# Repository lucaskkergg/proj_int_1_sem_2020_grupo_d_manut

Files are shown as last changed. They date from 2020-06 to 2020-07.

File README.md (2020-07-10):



# Projeto Integrador - Fatec São José dos Campos - Brasil

Projeto integrador de cunho tecnológico e desenvolvimental, o qual a atividade proposta foi desenvolver o "escopo" de uma ferramenta utilizada para a manutenção de uma aeronave.

## - Descrição das pastas:
* __ATAS:__ Contém as ATAS desenvolvidas durante o projeto;
* __Apresentações:__ Contém as apresentações desenvolvidas pelo grupo;
* __CAD:__ Contém os projetos 3D da peça;
* __Calculos:__ Contém os calculos aplicados e utilizados no projeto;
* __Documentos:__ Documentações importantes ao projeto;
* __Git_img:__ Pastá com arquivos para o "README";
* __Imagens:__ Contém imagens referentes ao projeto;
* __Grupo-Delta-Projeto-Integrador:__ Contém os arquivos solicitados pelo professor para avaliação do Pi.

## - Integrantes
* Christian Arilio Bezerra de Queiroz;
* Karen Roithmeier Rodrigues;
* Lucas Sergio de Oliveira;
* Marcio Siqueira Pereira;
* Mayara Carolina Ferreira de Lima;
* Paulo Henrique Conceição Dias.

## - Objetivo

Desenvolvimento de uma ferramenta proposta.

## - Estrutura 3D da mesma:

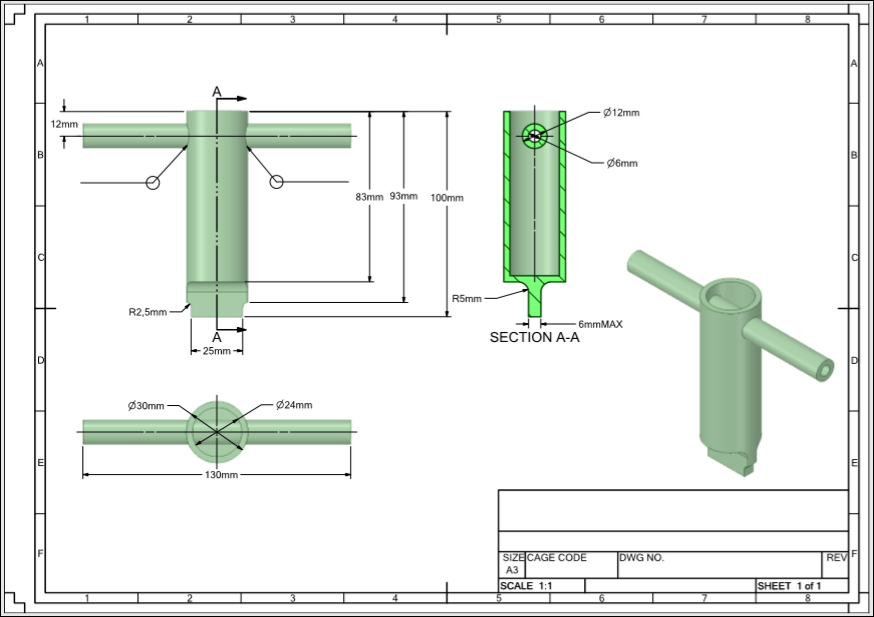
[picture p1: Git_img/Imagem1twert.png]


 ## - Link do vídeo:
 
 https://youtu.be/3H-tNPrEDUI
 ---------------------------------------------------------------------------------------------------------

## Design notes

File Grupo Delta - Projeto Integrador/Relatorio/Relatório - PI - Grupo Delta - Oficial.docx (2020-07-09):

FATEC – FACULDADE DE TECNOLOGIA DE SÃO JOSÉ DOS CAMPOS
PROF. JESSEN VIDAL

Chave de Retenção para Cilindro de Alta Pressão do Trem De Pouso Principal do Helicóptero Pantera

SÃO JOSÉ DOS CAMPOS / SP

1° Semestre - 2020

Chave de Retenção para Cilindro de Alta Pressão do Trem de Pouso Principal do Helicóptero Pantera

INTEGRANTES: CHRISTIAN ARILIO BEZERRA
DE QUEIROZ, KAREN ROITHMEIER RODRIGUES, LUCAS SERGIO DE OLIVEIRA, MÁRCIO SIQUEIRA PEREIRA, MAYARA CAROLINA FERREIRA DE LIMA, PAULO HENRIQUE CONCEIÇÃO DIAS

PROF. ORIENTADOR: ALEXANDRE ZARAMELA

PROF. CLIENTE: FELIX ARLINDO STROTTMANN

CURSO: TÉCNOLOGO EM MANUTENÇÃO DE AERONAVES

SÃO JOSÉ DOS CAMPOS / SP

1° Semestre - 2020

# 1. INTRODUÇÃO

O Projeto Integrador Transversal proposto pela FATEC – Faculdade de Tecnologia de São José dos Campos/SP, tem como objetivo promover ao aluno a oportunidade de desenvolvimento de suas habilidades através de um desafio real, que o leva através da prática a solucionar uma necessidade específica proposta.

No primeiro semestre de 2020, a turma de Manutenção de Aeronaves recém ingressada recebeu o desafio de projetar 5 (cinco) ferramentas que serão utilizadas no Laboratório para montagem e desmontagem do atuador do Trem de Pouso Principal do Helicóptero Pantera. Os alunos dividiram-se em 5 (cinco) grupos, sendo que cada um foi responsável por uma ferramenta específica, tendo como denominação os respectivos grupos: Alfa, Bravo, Charlie, Delta e Foxtrot.

O grupo do presente relatório, Delta, recebeu como desafio o desenvolvimento de projeto da ferramenta “Retaining Key for Cylinder” – Código: PN OU50400, conforme “CMM (Component Maintenance Manual) 32-12-96 Main Landing Gear Leg”. A ferramenta tem como objetivo realizar a montagem do trem de pouso principal retendo o cilindro de alta pressão para aperto de uma porca específica.

# 2. MATERIAIS E MÉTODOS

Após apresentação por parte do professor Félix Arlindo Strottmann e Alexandre Zaramela em relação ao Projeto Integrador Transversal, as turmas dirigiram-se ao laboratório da faculdade para que fosse possível analisar e tomar nota dos componentes que empregam o uso das ferramentas a serem desenvolvidas.

Foi observado o componente que receberia atuação da ferramenta PN OU50400 (figura 1) e, juntamente com o auxílio do CMM (Component Maintenance Manual) 32-12-96, foram realizadas as medições com o paquímetro do Rebaixo do Cilindro (figura 3) do Trem de Pouso Principal do Helicóptero Pantera (figura 2).

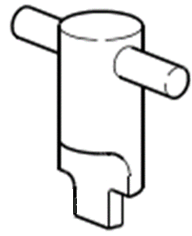
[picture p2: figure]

Figura 1 – Imagem da ferramenta: Chave de Retenção para Cilindro PN OU50400 – Manual CMM: 32-12-96.

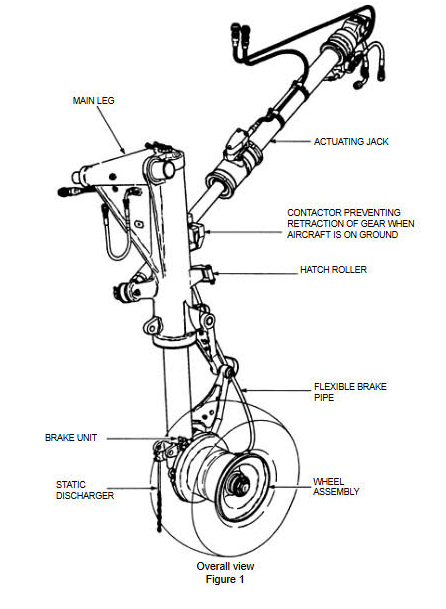
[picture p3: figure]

Figura 2 – Trem de Pouso Principal do Helicóptero Pantera - Manual CMM: 32-12-96, Pág. 39.

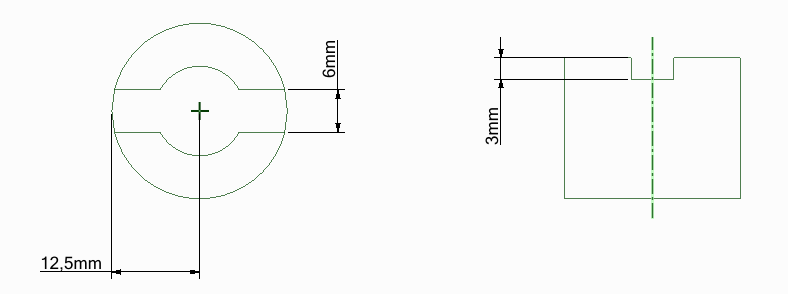
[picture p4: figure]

Figura 3 - Medidas do rebaixo de encaixe do dente da ferramenta no cilindro de alta pressão.

O grupo realizou a medição do Rebaixo no Cilindro, como ilustra a Figura 3, para que se fosse possível dar início ao processo de parametrização da ferramenta. Em posse destes dados, o grupo iniciou um processo de Engenharia reversa, procurando visualizar como era a ferramenta através de imagem presente no manual.

Com as medidas de referência relacionadas ao Dente da ferramenta e, a figura do manual representando como é a aparência da ferramenta, a imaginação entrou em cena, croquis começaram a ser desenvolvidos a mão e em seguida em softwares de modelagem CAD.

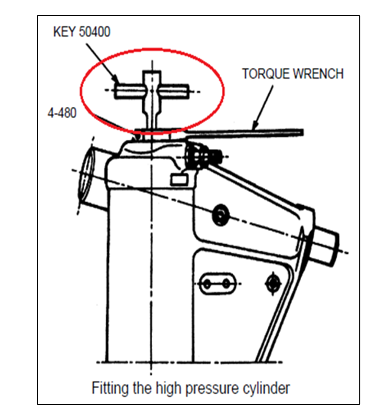
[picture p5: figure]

Figura 4 - Imagem da localização da ferramenta no Trem de Pouso – Manual CMM: 32-12-96.

Os croquis realizados manualmente proporcionaram uma ampla noção para partir à modelagem virtual da ferramenta no CAD. Durante o desenvolvimento do projeto, ocorreram diversas reuniões em grupo com o auxílio do professor orientador Alexandre Zaramela, com o intuito de melhoria dimensional e aproveitamento estrutural. Segue alguns exemplos quanto as dimensões da ferramenta no decorrer do projeto (Figura 5.0 a 5.3).

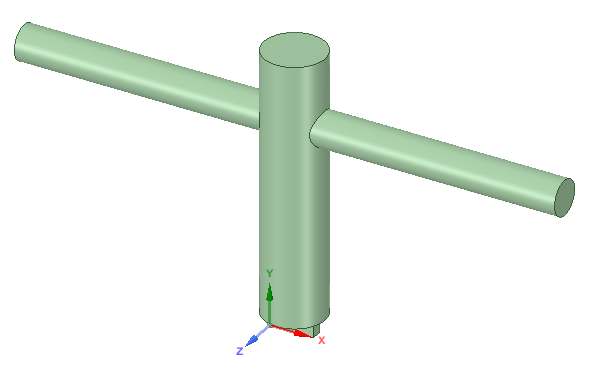
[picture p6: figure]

Figura 5.0 – Imagem do Primeiro Croqui no CAD, partindo do Desenho Técnico Manual – Autoria Própria. SpaceClaim

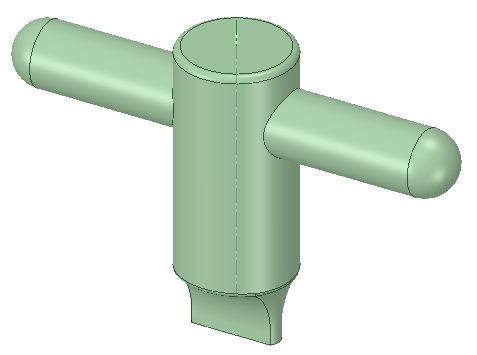
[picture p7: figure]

Figura 5.1 – Imagem do Croqui no CAD, atualizando as medidas com arredondamento na ponta da haste – Autoria Própria. SpaceClaim.

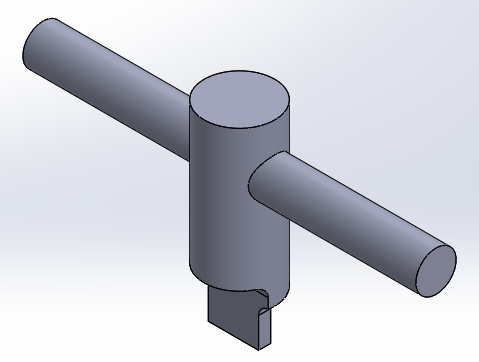
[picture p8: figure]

Figura 5.2 - Imagem do Croqui no CAD, com embasamento no CMM – Autoria Própria. SpaceClaim.

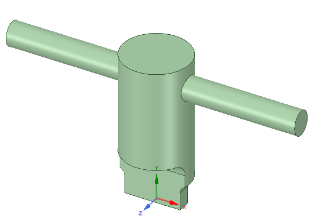
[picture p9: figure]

Figura 5.3 – Imagem do Croqui no CAD, redimensionamento da ferramenta – Autoria Própria. SpaceClaim.

Em uma primeira versão de projeto, as seguintes dimensões na figura abaixo (Figura 6) foram definidas para que se desse início aos cálculos estruturais da ferramenta.

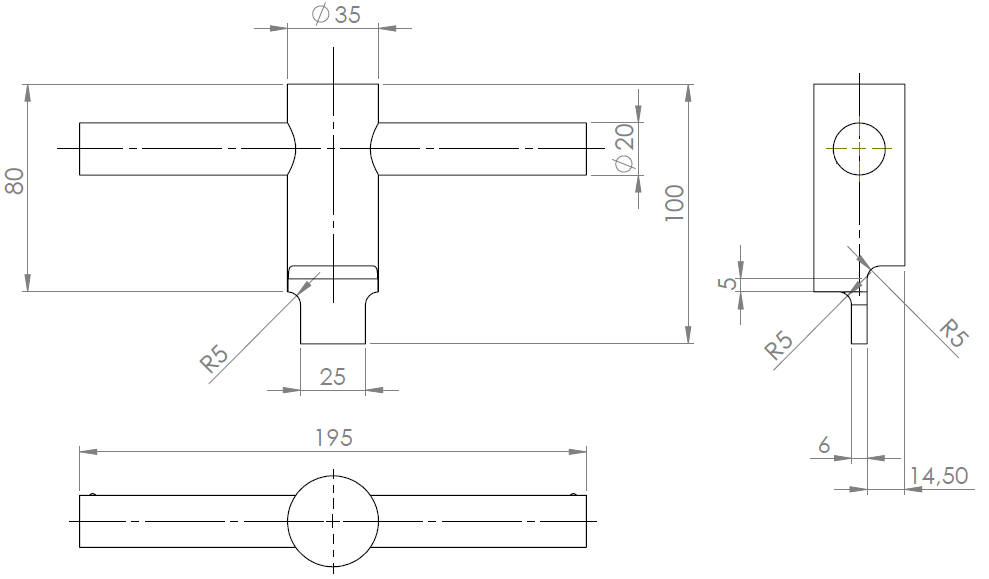
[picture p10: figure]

Figura 6 – Desenho Técnico – Dimensionamento da ferramenta. Autoria Própria. SpaceClaim.

Quanto a nomenclatura adotada para as partes da ferramenta, segue figura abaixo.

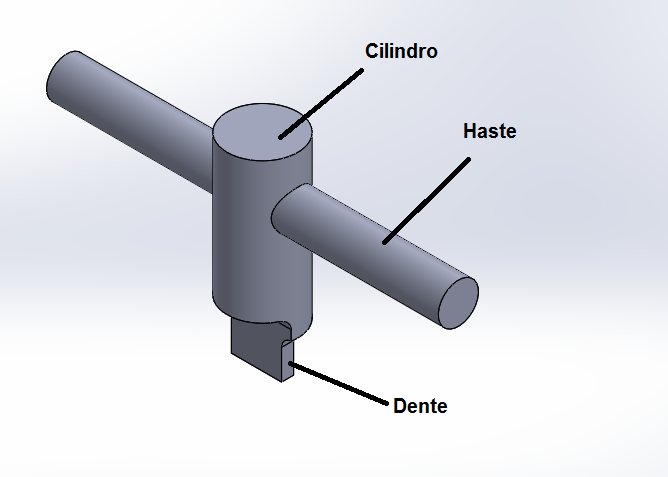
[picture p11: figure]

Figura 7 – Nomenclatura de partes da ferramenta. Autoria Própria. SpaceClaim.

Em relação ao material da ferramenta, foi escolhido o SAE 6150, Aço prata Cromo-Vanádio, pois através de pesquisas e observações em ambientes de trabalho essa liga de aço é a mais utilizada em ferramentas para esforços de torção. O Cromo nesta liga favorece a dureza e a proteção contra oxidação, enquanto o vanádio proporciona alta resistência quanto ao desgaste. Não é necessária a aplicação de tratamento, pois as propriedades mecânicas deste material atendem aos esforços que serão demonstrados adiante através dos cálculos com favorável Margem de Segurança.

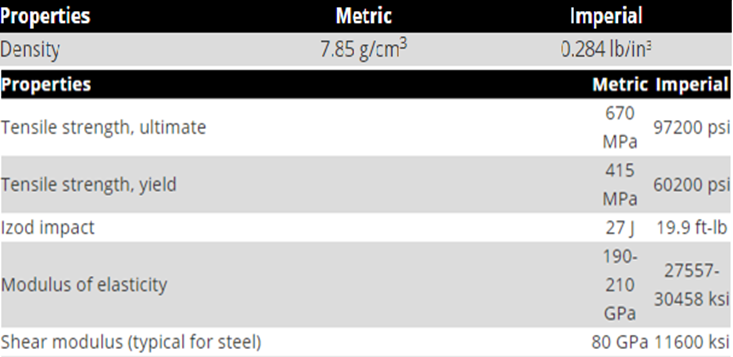
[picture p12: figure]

Propriedades Aço Cromo-Vanádio

. Tabela 1 – Propriedades do Aço. Azo Materials.

# 3. RESULTADOS

## 3.1 Primeira Revisão

Em posse das dimensões e do material, foram realizados os seguintes cálculos, nos quais foram desenvolvidos em planilhas eletrônicas, utilizando o Microsoft Excel. Todos os cálculos desenvolvidos no Excel possuem a coloração azul na célula quando é um Input para o cálculo e, dourado para o resultado após aplicação dos Inputs.

1. Cálculo de tensão de esmagamento na superfície de contato entre a ferramenta e o cilindro;
2. Cálculo de torção em barras de seção transversal não circular (torção no dente);
3. Cálculo de flexão em barras de seção circular (tensão na haste);
4. Cálculo de torção em barras de seção circular (torção no cilindro da chave);
5. Cálculo de margem de segurança.

### 3.1.1 Cálculos da Primeira Revisão

#### 3.1.1.1 Cálculo de Tensão de Esmagamento na Superfície de contato entre a Ferramenta e o Cilindro

O cálculo de Tensão de Esmagamento na superfície de contato entre a ferramenta e o cilindro foi realizado para que obtivesse o valor da Tensão de Cisalhamento entre o contato da ferramenta com o cilindro, para posterior avaliação quanto a resistência da ferramenta a este esforço sem deformação permanente. As seguintes equações foram utilizadas:

Equação 1 – Fórmula de Torque ou Momento Equação 2 – Fórmula de Tensão.

A Primeira Equação, sendo essa a fórmula do Torque/Momento (Nm), é dada pelo produto da Força em Newtons e “b”, sendo o Braço em metros. A Segunda Equação representa o cálculo da Tensão, sendo “t” a Tensão em (N/mm²) e A a Área em m². Segundo o CMM o Torque de aperto da Chave de Retenção é de 20Nm, utilizando as fórmulas e os valores de dimensionamento obteve-se os seguintes resultados:

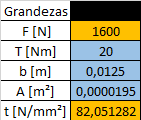
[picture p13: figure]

Cálculo Tensão de Esmagamento no contato do Dente

Tabela 2 –. Autoria própria - Microsoft Excel.

#### 3.1.1.2 Cálculo de Torção em Barras de Seção Transversal não Circular (Torção no Dente)

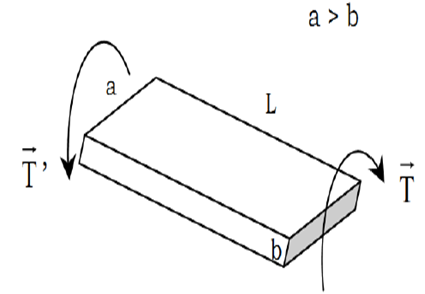
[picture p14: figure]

Figura 8 - Representação do esforço em barra não circular.

O cálculo de Torção em Barras de Seção Transversal não Circular foi necessário para avaliar a Tensão de Cisalhamento no dente da ferramenta e a sua mudança no ângulo de Torção, quanto o torque de 20Nm fornecido pelo material que fosse aplicado. As seguintes equações foram utilizadas:

Equação 3 – Cálculo de tensão máxima de cisalhamento em esforço de torção em barras não circulares.

Equação 4 – Cálculo do ângulo de torção em barras não circulares.

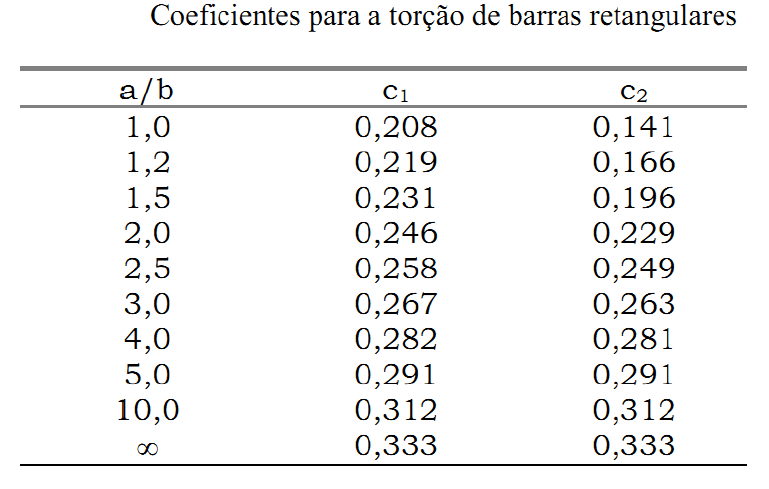
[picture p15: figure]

Tabela 3 – Coeficientes para a Torção de Barras Regulares.

A Equação 3 é a fórmula de cálculo de tensão máxima de cisalhamento em esforço de torção em barras não circulares, de unidade Pa. A Equação 4 é a fórmula do cálculo do ângulo de torção em barras não circulares, de unidade radianos.

Os seguintes resultados foram obtidos:

Cálculo Tensão Máxima de Cisalhamento e ângulo de torção.

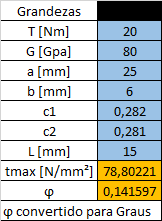
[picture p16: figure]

Tabela 4 - Autoria própria - Microsoft Excel.

#### 3.1.1.3 Cálculo de Flexão em Barras de Seção Circular (Tensão na Haste)

O cálculo de Flexão em Barras de Seção Circular foi necessário para obter a Máxima Tensão de Flexão no contato entre a haste e o cilindro da ferramenta. Para isso, foi calculado a força F1 na extremidade da haste necessária para um Torque/Momento resultante de 20Nm no centro da ferramenta, com esta força, foi calculado o Torque/Momento T2 atuante na junção entre a haste e o cilindro e, com este valor de Torque/Momento aplicado nas fórmulas a seguir, foi possível determinar a tensão de flexão na haste. Além do Cálculo de Toque, também foram utilizadas as seguintes equações:

Equação 5 – Cálculo do momento de inércia para circunferência.

Equação 6 - Cálculo do módulo resistente de flexão.

Equação 7 – Cálculo da tensão de flexão na haste.

A Equação 5 representada é o Cálculo usado no Momento de Inércia para uma Circunferência, onde “d” é o diâmetro da circunferência. A Equação 6 é o Cálculo do Módulo Resistente de Flexão, sendo “I” o momento de inércia e “c” a distância da linha neutra da circunferência até a extremidade, similar ao raio da circunferência. A Equação 7 é o Cálculo da Tensão de Flexão na Haste no contato com o cilindro da ferramenta, onde “M” é o Torque/Momento calculado e “w” é o módulo resistente.

Os seguintes resultados foram obtidos:

Cálculo da força na extremidade da haste

Tabela 5 – Autoria própria. - Microsoft Excel.

Cálculo do Torque/Momento na junção da Haste com o Cilindro da Ferramenta

Tabela 6 – Autoria própria. - Microsoft Excel.

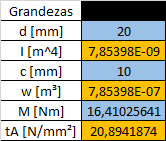
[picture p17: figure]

Cálculo da Tensão de Flexão na Haste

Tabela 7 – Autoria própria. - Microsoft Excel.

3.1.1.4 Cálculo de Torção em Barras de Seção Circular (Torção no Cilindro da Chave)

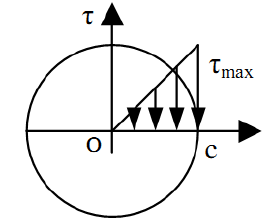
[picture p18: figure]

Figura 9 – Representação da Distribuição da Tensões de Cisalhamento na Seção Transversal de eixo circular maciço.

O Cálculo de Torção em Barras e Seção Circular foi necessário para calcular a tensão de cisalhamento por torção no cilindro da ferramenta. Para isso, foi encontrado o momento polar de inércia de uma circunferência, seguido da tensão máxima na extremidade do cilindro. As seguintes equações foram utilizadas:

Equação 8 – Cálculo do Momento de Inércia Polar De Um Eixo Circular Maciço.

Equação 9 – Cálculo da tensão máxima de torção no cilindro.

A Equação 8 é o cálculo de momento de inércia polar de um eixo circular maciço, onde c é a distância equivalente ao raio da circunferência. A Equação 9 é o cálculo da tensão máxima de torção no cilindro da ferramenta, onde T é o Torque/Momento, c é a distância equivalente ao raio da circunferência e J é o momento de inércia polar.

Os seguintes resultados foram obtidos:

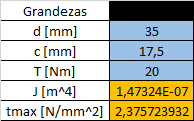
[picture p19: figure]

Cálculo da torção no cilindro da ferramenta

Tabela 8 – Autoria própria - Microsoft Excel.

#### 3.1.1.5 Cálculo de Margem de Segurança

O cálculo de margem de segurança foi necessário para demonstrar se de fato a configuração atual da ferramenta resiste aos esforços nela empregados, define-se como a razão entre a tensão atuante e a tensão de escoamento da peça, subtraído do número inteiro 1 e demonstrado em porcentagem. A seguinte fórmula foi utilizada:

Equação 10 – Cálculo da Margem de Segurança para Tensão de Escoamento.

A Equação acima é o cálculo da Margem de Segurança para tensão de escoamento, onde t é a tensão atuante e ts é a tensão de escoamento do material utilizado, o Aço Cromo-Vanádio. Os seguintes resultados foram obtidos:

Cálculo da margem de segurança das partes da ferramenta

Tabela 9 – Autoria própria - Microsoft Excel.

Esta configuração se mostrou bastante robusta observando o cálculo de margem de segurança, ou seja, existe margem para alteração da ferramenta sem comprometer sua capacidade de atender aos esforços de trabalho.

Um protótipo em madeira foi confeccionado, o grupo percebeu que o diâmetro do cilindro da ferramenta de 35 mm carecia de ergonomia, e a haste poderia ser reduzida e possuir menor diâmetro.

Foi observado que a massa final desta ferramenta mensurada no software CAD Ansys SpaceClaim aproximava-se de 1kg, o grupo chegou à conclusão que a ferramenta estava por demais superdimensionada, sendo assim, após orientações do professor orientador Alexandre Zaramela, foi reconfigurada as dimensões da ferramenta, e também ficou definido que a nova configuração seria vazada, e não mais maciça. Aplicando este Trade-Off, foi retirada massa da ferramenta e melhorada ergonomicamente.

## 3.2 Segunda Revisão

Após aplicadas mudanças de dimensionamento da ferramenta, extração de material para alívio de massa, e remodelagem do dente para uma condição simétrica, a nova e definitiva configuração da ferramenta ficou como demonstra a figura abaixo:

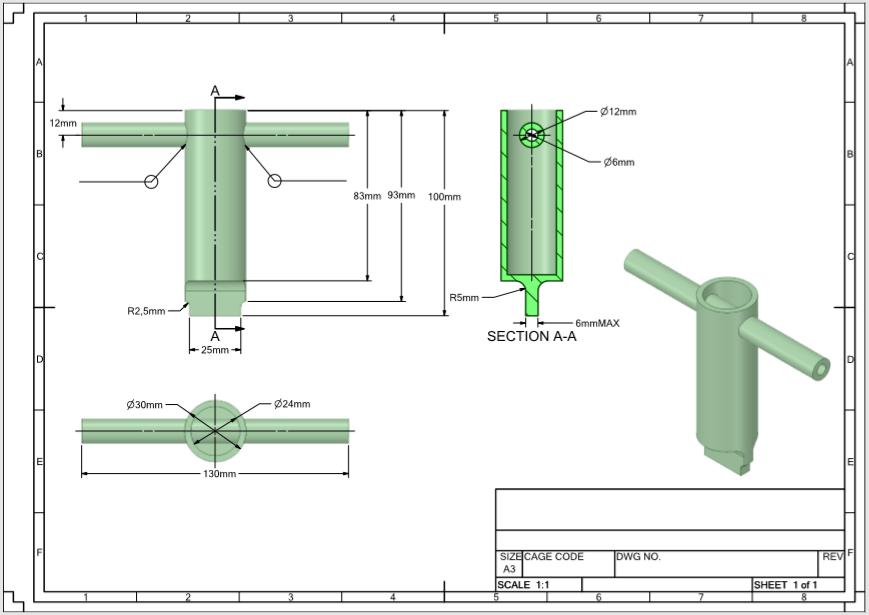
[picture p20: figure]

Figura 10 – Desenho dimensional da ferramenta após Trade-Off. Autoria própria. SpaceClaim.

### 3.2.1 Cálculos da Segunda Revisão

Os cálculos foram realizados novamente adequando-se as novas dimensões, com inserção de um cálculo de margem de segurança para ruptura no cálculo de tensão na haste. A seguir serão demonstrados os resultados após os novos cálculos.

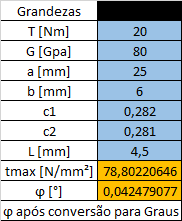
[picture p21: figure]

#### 3.2.1.1 Cálculo de torção em barras de seção transversal não circular (torção no dente)

Tensão de Torção e Ângulo de Torção.

Tabela 10 – Autoria própria - Microsoft Excel.

#### 3.2.1.2 Cálculo de flexão em barras de seção circular (tensão na haste)

Neste cálculo, foi implementado o fator de segurança de valor 2, ou seja, a Força calculada foi multiplicada por 2 e, a tensão calculada baseia-se nesta força com aplicação do fator.

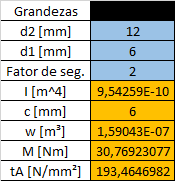
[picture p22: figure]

Cálculo de Flexão na Haste com o Fator de Segurança

Tabela 11 – Autoria própria - Microsoft Excel.

Cálculo de Momento na Junção da Haste com o Cilindro

Tabela 12 – Autoria própria - Microsoft Excel.

Cálculo de Força na Haste

Tabela 13 – Autoria própria - Microsoft Excel.

#### 3.2.1.3 Cálculo de torção em barras de seção circular (torção no cilindro da chave)

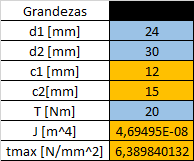
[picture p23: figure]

Cálculo de Torção no Cilindro da Ferramenta

Tabela 14 – Autoria própria - Microsoft Excel.

#### 3.2.1.4 Cálculo de Margem de Segurança

O Cálculo similar ao da ferramenta anterior, porém foi atualizado com a adição do cálculo de Margem de Segurança para Ruptura, para parte da ferramenta que sofre flexão, a haste.

Equação 11 - Margem de segurança para ruptura.

Tabela 15 – Cálculo da Margem de Segurança - Cisalhamento. Autoria própria. Microsoft Excel.

Tabela 16 – Cálculo da Margem de Segurança - Ruptura. Autoria própria. Microsoft Excel.

## 3.3 Resultado Definitivo

Após a aplicação do Trade-Off, obteve-se uma ferramenta capaz de atender aos esforços necessários, com a massa de aproximadamente 280g. A Margem de Segurança obtida após a melhoria ainda é bastante satisfatória e, demonstra que a ferramenta é robusta e possui uma ótima otimização.

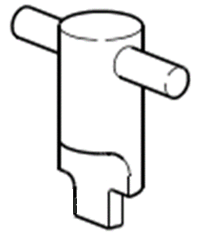
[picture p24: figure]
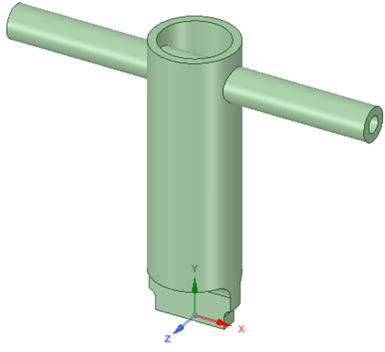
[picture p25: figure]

Figura 11 – Comparação da ferramenta observada no CMM com a ferramenta projetada pelo grupo Delta. Autoria própria. SpaceClaim.

# 4. CONCLUSÕES

O Projeto Integrador Transversal do Primeiro Semestre de 2020 proporcionou aos alunos uma oportunidade real de desenvolvimento do aprendizado através da prática, apresentou uma necessidade na qual o grupo pôde se reunir e em equipe planejarem e executarem os desafios que lhes foram impostos. Em consequência, este projeto não só desenvolveu o aprendizado dos alunos, como também promoveu o relacionamento interpessoal de cada participante, um dos grandes objetivos do Projeto Integrador.

A ferramenta desenvolvida no projeto demonstra solucionar a necessidade existente no laboratório para montagem do trem de pouso principal do Helicóptero Pantera, o grupo atingiu o objetivo que almejava.

O auxílio dos professores durante o desenvolvimento do projeto foi essencial para o resultado obtido, a interação aluno-professor foi bem fluída, o que acabou por garantir um avanço e conclusão de projeto com elevado nível de satisfação.

# 5. REFERÊNCIAS

Messier – Dowty SA. CMM (Component Maintenance Manual with Illustrated Parts List) 32-12-96 Main Landing Gear Leg. São Paulo: 2020.

NADAL. Prof. Dr. Carlos Aurélio. Estudo sobre Torção. Torção em Barras de Secção Transversal não Circular. Universidade Federal do Paraná. Disponível em: http://www.cartografica.ufpr.br/portal/wp-content/uploads/2015/09/AULA-04-TOR%C
3%87%C3%83O.pdf – Acesso em: 2020.

Educação, Tecnologia e Engenharia – Tecnologia e Engenharia Online. Resistencia dos Materiais: Flexão em Secção Circular. Disponível em: https://www.youtube.com
/watch?v=cYZEnVjWnoU&t= (https://www.youtube.com/watch?v=cYZEnVjWnoU&t=) - Acesso em: 2020.

AISI 6150 Alloy Steel (UNS G61500) – Azo Materials. Propriedades do Aço 6150. Disponível em: https://www.azom.com/article.aspx?ArticleID=6744 – Acesso: 2020.

ECIVIL. Descomplicando Engenharia. Módulo de Resistencia. Disponível em: https://
www.ecivilnet.com/dicionario/o-que-e-modulo-de-resistencia.html - Acesso em: 2020.

Histórico do Projeto Integrador Transversal, grupo Delta. Cálculos; Pesquisas; ATA; Desenhos Técnicos; Repositório do GITHUB. Disponível em: https://github.com/
lucaskkergg/proj_int_1_sem_2020_grupo_d_manut (https://github.com/lucaskkergg/proj_int_1_sem_2020_grupo_d_manut) – Acesso: 2020.

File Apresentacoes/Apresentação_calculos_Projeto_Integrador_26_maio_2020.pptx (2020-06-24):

## Fatec S.J.C


Prof. Cliente: Felix Strottmann
Prof. Orientador: Alexandre Zaramela

Projeto integrador transversal:
- Chave de retenção para cilindro

Nomes dos integrantes:
- Christian Arilio Bezerra de Queiroz
- Lucas Sergio de Oliveira
- Mayara Carolina Ferreira de Lima
- Karen Roithmeier Rodrigues
- Antônio Carlos de Oliveira Carvalho Ferreira
- Paulo Henrique Conceição Dias
- André Luiz Ribeiro


## Ferramenta e conjunto


- Montagem do cilindro de alta pressão
- Aperto de porca


## Comparação


Ferramenta retirada do CMM


Primeiro Croquis apresentado


Ferramenta após orientações

## Cotas


## Cálculo da tensão na superfície de contato


T = Torque [Nm]
t = Tensão [N/mm²]
F = Força [N]
A = Área [m²]
b = Braço [m]

## Cálculo de torção em barras de seção transversal não circular


T = Torque [Nm]
tmax = Tensão máxima de cisalhamento [N/mm²]
G = Módulo de elasticidade transversal [Pa]
φ = Ângulo de torção

## Tensão na haste (Flexão em seção circular)


M = Momento [Nm]
tA = Tensão no ponto A [N/mm²]
I = Momento de inércia [m^4]
w = Módulo resistente [m³]
C = Distância ponto A para linha neutra [m]
d = Diâmetro [m]

***O Módulo de resistência à Flexão é a característica geométrica da seção de uma viga que se opõe à flexão.

## Torção no cilindro da Chave


T = Torque [Nm]
tmax = Tensão máxima de torção [N/mm²]
J = Momento de inércia polar [m^4]
C = Distância ponto A para linha neutra [m]

## Margem de segurança

Ms = Margem de segurança
t = Tensão da peça[N/mm²]
ts = Tensão de escoamento do material[N/mm²]

## Ferramenta em perspectiva


## Propriedades LIGA DE AÇO AISI 6150


## Referências

- Torção em barras de seção transversal não circular
  - http://www.cartografica.ufpr.br/portal/wp-content/uploads/2015/09/AULA-04-TOR%C3%87%C3%83O.pdf
- Flexão em seção circular
  - https://www.youtube.com/watch?v=cYZEnVjWnoU&t=
- Propriedades do aço 6150
  - https://www.azom.com/article.aspx?ArticleID=6744
- Módulo resistente
  - https://www.ecivilnet.com/dicionario/o-que-e-modulo-de-resistencia.html

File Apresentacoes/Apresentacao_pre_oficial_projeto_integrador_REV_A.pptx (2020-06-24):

## Fatec S.J.C Grupo Delta


Prof. Cliente: Felix Strottmann
Prof. Orientador: Alexandre Zaramela

Projeto integrador transversal:
- Chave de retenção para cilindro

Nomes dos integrantes:
- Christian Arilio Bezerra de Queiroz
- Lucas Sergio de Oliveira
- Mayara Carolina Ferreira de Lima
- Marcio Siqueira Pereira
- Karen Roithmeier Rodrigues
- Paulo Henrique Conceição Dias

## Sumário

1. Projeto Integrador Transversal
2. Ferramenta e sua necessidade
3. Desenho dimensional da ferramenta
4. Material escolhido para a Ferramenta
5. Desenvolvimento analítico
6. Evolução do projeto e Trade-Off
7. Resultado Final
8. Conclusão

Série de Padrões de Integração | Fernando Franzini Blog
Trilha de Liderança: Gestão por pessoas ou resultados? – Grupo Am3

## 1 – Projeto Integrador Transversal

- Objetivo do projeto
- Grupos participantes
- Ferramentas dos grupos
- Ferramenta do grupo Delta

Helibras entrega Pantera K2 que foi modernizado no Brasil

## 2 – Ferramenta e sua necessidade


Utilizando a chave de retenção do cilindro de alta pressão 50400, aperte a porca (4-480)
(Torque de aperto: 20 N.m (14 lbf.ft)).

## 3 – Desenho dimensional da ferramenta


## 4 – Material escolhido para a ferramenta

- Aço Cromo – Vanádio SAE 6150
  - Observação de ferramentas em ambiente de trabalho;
  - Pesquisa de materiais de ferramentas de aperto existentes no mercado;
  - Cromo oferece dureza e proteção contra oxidação;
  - Vanádio proporciona resistência ao desgaste.


## 5 – Desenvolvimento analítico

- Cálculo de tensão de esmagamento na superfície de contato entre a ferramenta e o cilindro;
- Cálculo de torção em barras de seção transversal não circular (torção no dente);
- Cálculo de flexão em barras de seção circular (tensão na haste);
- Cálculo de torção em barras de seção circular (torção no cilindro da chave);
- Cálculo de margem de segurança.


## 5 – Desenvolvimento analítico Cálculo de tensão de esmagamento na superfície de contato entre a ferramenta e o cilindro


T = Torque [Nm]
t = Tensão [N/mm²]
F = Força [N]
A = Área [m²]
b = Braço [m]

## 5 – Desenvolvimento analítico Cálculo de torção em barras de seção transversal não circular (torção no dente)


## 5 – Desenvolvimento analítico Cálculo de flexão em barras de seção circular (tensão na haste)


## 5 – Desenvolvimento analítico Cálculo de torção em barras de seção circular (torção no cilindro da chave)


## 5 – Desenvolvimento analítico Cálculo de margem de segurança


## 6 – Evolução do projeto e Trade-Off

- Observando CMM
- Modelando croquis
- Acompanhamento em aula
- 1° Protótipo
- Otimização ergométrica
- Alivio de massa

## 6 – Evolução do projeto e Trade-Off


## 7 – Resultado Final

## 8 – Conclusão

- Desafio
- Trabalho em equipe
- Desenvolvimento interpessoal
- Aprendizado na prática
- Produto final

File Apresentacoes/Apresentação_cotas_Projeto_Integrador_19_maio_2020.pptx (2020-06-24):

## Fatec S.J.C


Prof. Cliente: Felix Strottmann
Prof. Orientador: Alexandre Zaramela

Projeto integrador transversal:
- Chave de retenção para cilindro

Nomes dos integrantes:
- Christian Arilio Bezerra de Queiroz
- Lucas Sergio de Oliveira
- Mayara Carolina Ferreira de Lima
- Karen Roithmeier Rodrigues
- Antônio Carlos de Oliveira Carvalho Ferreira
- Paulo Henrique Conceição Dias
- André Luiz Ribeiro


## Ferramenta e conjunto


- Montagem do cilindro de alta pressão
- Aperto de porca


## 1° Croquis resultante


## Comparação

Ferramenta retirada do CMM

Primeiro Croquis apresentado


Ferramenta após orientações

## Cotas


## Protótipo


## Cálculo da tensão na superfície de contato


## Cálculo de torção em barras de seção transversal não circular


## Tensão na haste (Flexão em seção circular)


## Tensão no cilindro da Chave

## Propriedades LIGA DE AÇO AISI 6150


## Referências

- Torção em barras de seção transversal não circular
  - http://www.cartografica.ufpr.br/portal/wp-content/uploads/2015/09/AULA-04-TOR%C3%87%C3%83O.pdf
- Flexão em seção circular
  - https://www.youtube.com/watch?v=cYZEnVjWnoU&t=
- Propriedades do aço 6150
  - https://www.azom.com/article.aspx?ArticleID=6744

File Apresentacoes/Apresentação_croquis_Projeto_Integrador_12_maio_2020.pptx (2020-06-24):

## Fatec S.J.C


Prof. Cliente: Felix Strottmann
Prof. Orientador: Alexandre Zaramela

Projeto integrador transversal:
- Chave de retenção para cilindro

Nomes dos integrantes:
- Christian Arilio Bezerra de Queiroz
- Lucas Sergio de Oliveira
- Mayara Carolina Ferreira de Lima
- Karen Roithmeier Rodrigues
- Antônio Carlos de Oliveira Carvalho Ferreira
- Paulo Henrique Conceição Dias
- André Luiz Ribeiro


## Ferramenta e conjunto


- Montagem do cilindro de alta pressão
- Aperto de porca


## Evolução do Croquis


1


2


3


4

## Croquis resultante


## Material e Tratamento Térmico

- Aço Cromo-Vanádio SAE 61XX
  - Observação de ferramentas em ambiente de trabalho;
  - Pesquisa de materiais de ferramentas de aperto existentes no mercado;
  - Cromo oferece dureza e proteção contra oxidação;
  - Vanádio proporciona resistência ao desgaste.
- Tratamento térmico
  - Tempera (Aumento da dureza e resistência na área de contato da ferramenta);
  - Revenimento (Aumento da tenacidade e correção da dureza excessiva).

Óleo para Têmpera de Aço KTALO 20 TN
Revenimento aço inox - Tratamento Térmico

## FIM

## Referências

- Aço cromo vanádio
  - https://www.foxlux.com.br/blog/dicas/as-propriedades-do-cromo-vanadio/
  - https://pt.wikipedia.org/wiki/Classifica%C3%A7%C3%A3o_SAE#SAE_6XXX_%E2%80%93_a%C3%A7o-Cromo-Van%C3%A1dio
  - https://armazemdtudo.com.br/blog/post/ferramentas-de-aco-cromo-vanadio-ou-carbono-askeyMi01LTItMC0wLWM_
- Tratamento térmico
  - http://tratamentotermico.com/tempera.html
  - http://tratamentotermico.com/revenimento.html

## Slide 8

- Padrão para apresentação de 3a feira:
- Slide 1 - Dados do grupo, Faculdade, Prof. cliente, Prof. orientador, etc. Nome do projeto.
- Slide 2 - Ilustração/Foto capturada do CMM do local da peça do grupo, qual a localização dela no conjunto.
- Slide 3 - Desenho do Croqui do grupo, à mão livre ou CAD. Vista isométrica e/ou projeções ortogonais, com régua e esquadros ou à mão livre.
- Slide 4 - Material, Tratamento Térmico, origem do material, etc.
- Slide 5 - FIM

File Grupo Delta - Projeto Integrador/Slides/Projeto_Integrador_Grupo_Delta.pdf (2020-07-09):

08/07/2020

1


# Grupo Delta

Projeto integrador transversal:

Chave de retenção para cilindro


Prof. Cliente: Felix Strottmann
Prof. Orientador: Alexandre Zaramela

Nomes dos integrantes:

Christian Arilio Bezerra de Queiroz Lucas Sergio de Oliveira
Mayara Carolina Ferreira de Lima Márcio Siqueira Pereira
Karen Roithmeier Rodrigues Paulo Henrique Conceição Dias

## Sumário

### 1. Projeto Integrador Transversal

### 2. Ferramenta e sua necessidade

### 3. Desenho dimensional da ferramenta

### 4. Material escolhido para a Ferramenta

### 5. Desenvolvimento analítico

### 6. Evolução do projeto e Trade-Off

### 7. Resultado Final

### 8. Conclusão

1 2

2

* Objetivo do projeto

* Grupos participantes

* Ferramentas dos grupos


* Ferramenta do grupo Delta

1 - Projeto Integrador Universal | Chave de retenção para cilindro


3 4

3

## Perna do Trem de Pouso Principal


Utilizando a chave de retenção do cilindro de alta pressão 50400 aperte a porca (4-480) (Torque de aperto: 20 N.m (14 lbf.ft).

## 2 - Ferramenta e suas necessidades

Chave de retenção para cilindro (470)

Component Maintenance Manual


5 6

4

3 – Desenho dimensional da ferramenta | 4 – Material escolhido para a ferramenta
| Aço Cromo – Vanádio SAE 6150
| * Observação de ferramentas em ambiente de trabalho; *Pesquisa de materiais de ferramentas de aperto existentes no mercado; * Cromo oferece dureza e proteção contra oxidação; *Vanádio proporciona resistência ao desgaste.


7 8


5

- Cálculo de tensão de esmagamento na superfície de contato entre a ferramenta e o cilindro; • Cálculo de torção em barras de seção transversal


não circular (torção no dente); • Cálculo de flexão em barras de seção circular

(tensão na haste); • Cálculo de torção em barras de seção circular

(torção no cilindro da chave); • Cálculo de margem de segurança.

## 5 – Desenvolvimento analítico Cálculo de tensão de esmagamento na superfície de contato entre a ferramenta e o cilindro

T = Torque [Nm]
t = Tensão [N/mm²]
F = Força [N]
A = Área [m²]
b = Braço [m]

9 10

6

Cálculo de torção em barras de seção transversal não circular (torção no dente) | Cálculo de flexão em barras de seção circular (tensão na haste)


| 1 – Referência com o centro

2 – Referência com a haste


11 12

7

Cálculo de torção em barras de seção circular (torção no cilindro da chave) | Cálculo de margem de segurança


13 14


8

* Observando CMM

* Modelando croquis

* Acompanhamento em aula

* 1° Protótipo

* Otimização ergométrica

* Alivio de massa

## 6 – Evolução do projeto e Trade-Off


15 16

9

7 – Resultado Final | 8 - Conclusão
| * Desafio * Trabalho em equipe * Desenvolvimento interpessoal * Aprendizado na prática * Produto final


17 18

10

## Referências

Link do GitHub
https://github.com

Torção em barras de seção transversal não circular http://www.cartografica.ufpr.br

Flexão em seção circular
https://www.youtube.com

Propriedades do aço 6150
https://www.azom.com

Módulo resistente
https://www.ecivilnet.com

19

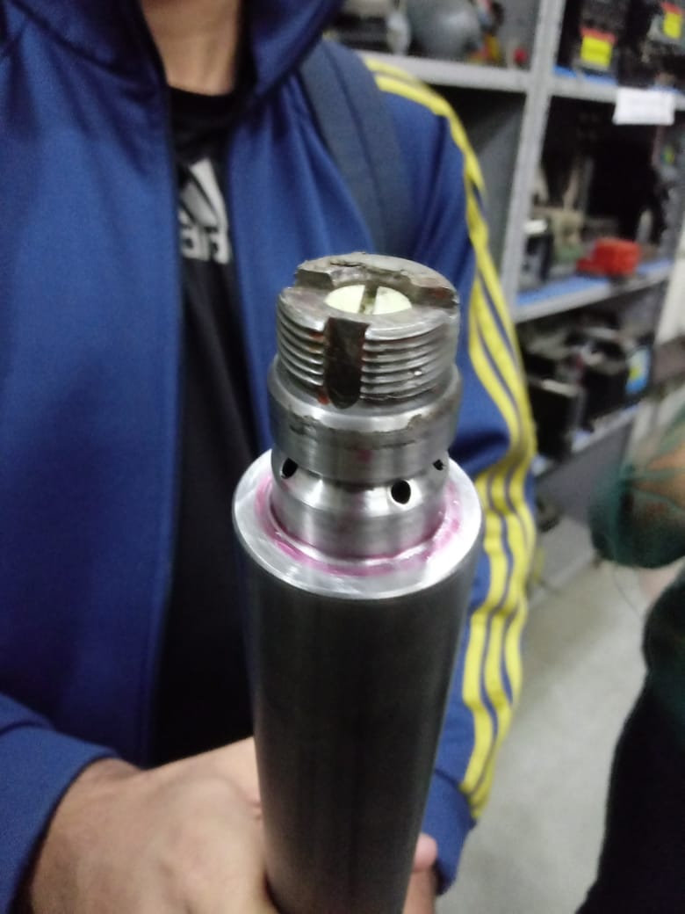
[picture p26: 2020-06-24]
Imagens/Laboratorio/cilindro_de_alta_pressão_perspectiva.jpeg

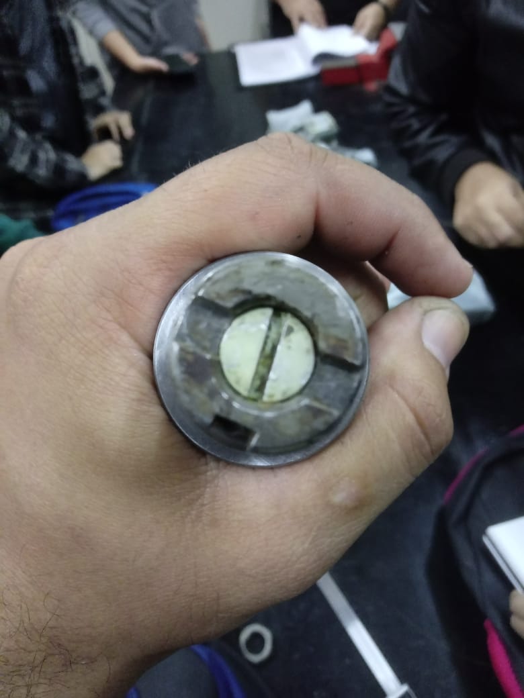
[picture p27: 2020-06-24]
Imagens/Laboratorio/cilindro_de_alta_pressão_superior.jpg

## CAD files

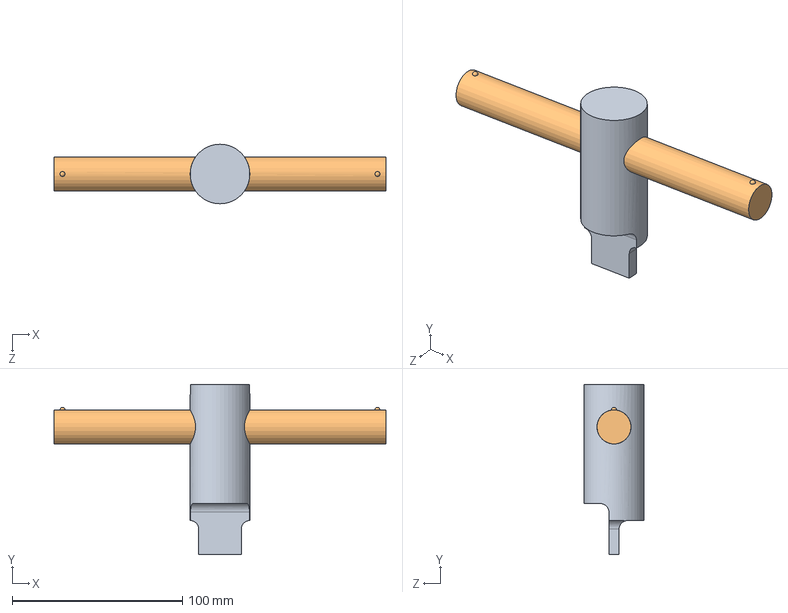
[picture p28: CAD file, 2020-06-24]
CAD/Croquis 3D/SolidWorks/Montagem_chave_de_retencao_cilindro_pantera.SLDASM
195.0 x 100.0 x 35.0 mm
Chave
Haste

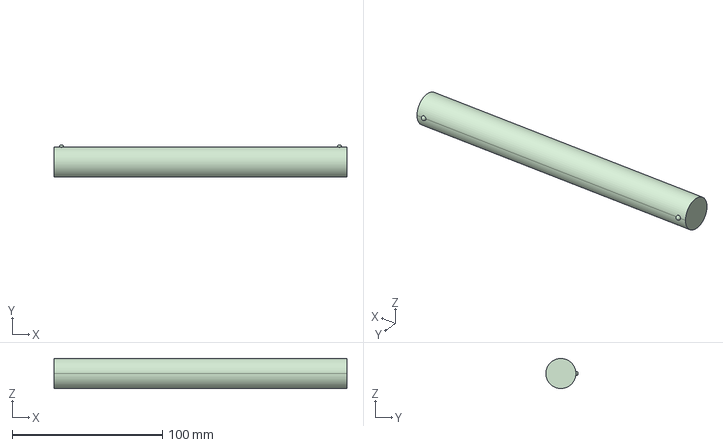
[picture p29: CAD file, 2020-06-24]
CAD/Croquis 3D/Haste.stp
195.0 x 21.5 x 20.0 mm

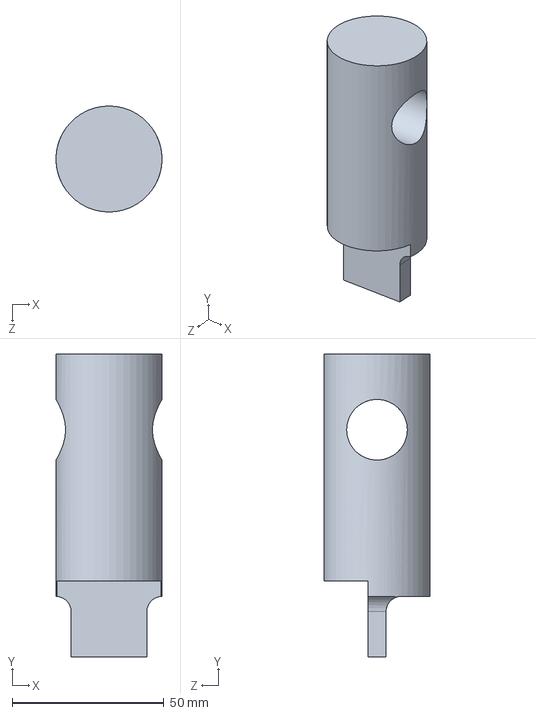
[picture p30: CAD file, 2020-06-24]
CAD/Croquis 3D/SolidWorks/bkp/Chave.SLDPRT
35.0 x 100.0 x 35.0 mm

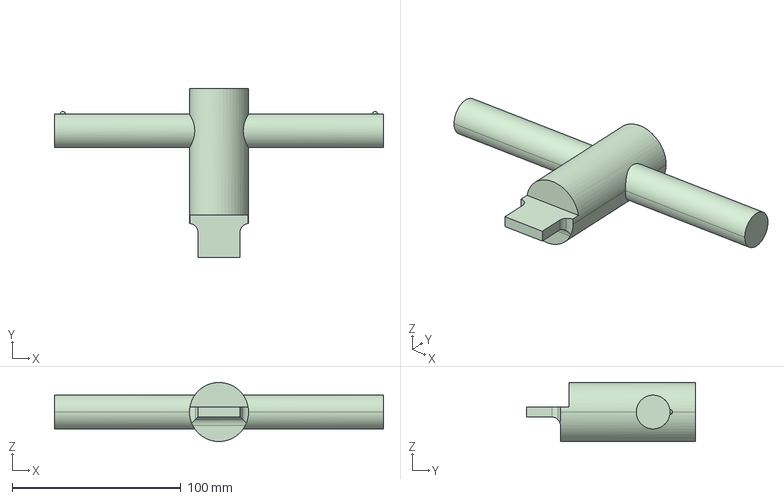
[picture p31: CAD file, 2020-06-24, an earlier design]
CAD/Obsoletos/Chave_de_retencao_para_cilindro_rev_A.stp
195.0 x 100.0 x 35.0 mm

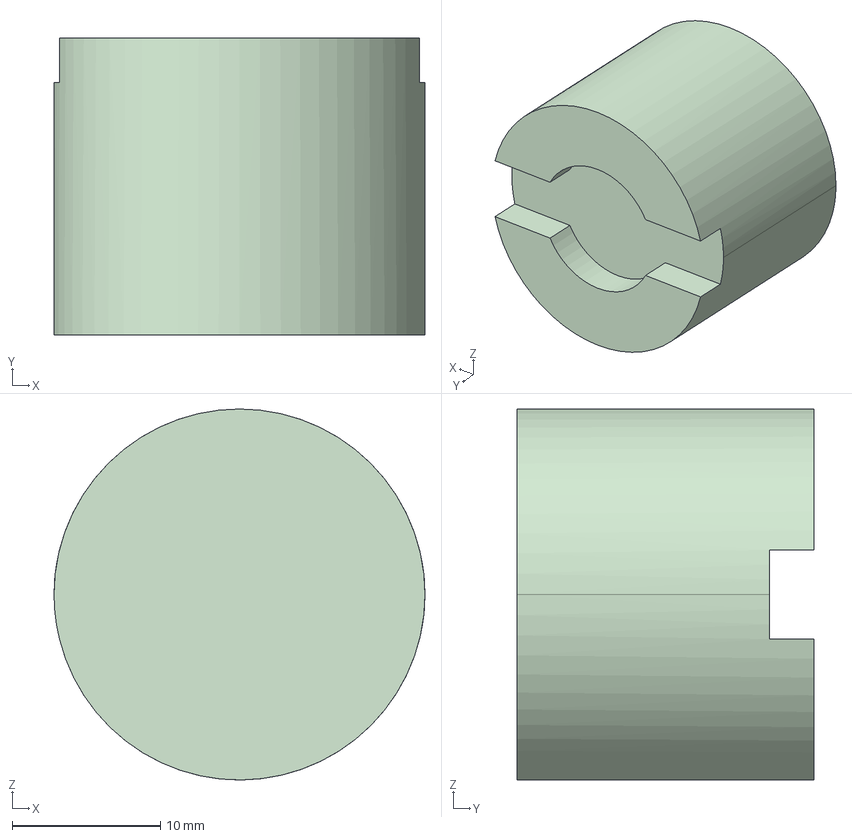
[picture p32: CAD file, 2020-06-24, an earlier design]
CAD/Obsoletos/Representacao_cilindro_alta_pressao.stp
25.0 x 20.0 x 25.0 mm

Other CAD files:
CAD/Croquis 3D/Chave_de_retencao_para_cilindro_rev_b.stp
CAD/Croquis 3D/SolidWorks/bkp/Chave_de_retencao_para_cilindro_rev_b.SLDPRT
CAD/Croquis 3D/SolidWorks/Chave.stp
CAD/Obsoletos/Chave_de_retencao_para_cilindro_rev_b.stp
CAD/Obsoletos/SolidWorks/bkp/Chave_de_retencao_para_cilindro_rev_b.SLDPRT
CAD/Obsoletos/SolidWorks/Chave.stp
CAD/Croquis 3D/Chave_de_retencao_para_cilindro_rev_A.SLDPRT
CAD/Croquis 3D/SolidWorks/Chave.SLDPRT
CAD/Croquis 3D/SolidWorks/Haste.SLDPRT
CAD/Croquis 3D/SolidWorks/Montagem_chave_de_retencao_cilindro_pantera.SLDDRW
CAD/Croquis 3D/SolidWorks/Montagem_chave_de_retencao_cilindro_pantera2.SLDDRW
CAD/Obsoletos/Chave_de_retencao_para_cilindro_rev_A.SLDPRT
CAD/Obsoletos/Representacao_cilindro_alta_pressao.SLDDRW
CAD/Obsoletos/Representacao_cilindro_alta_pressao.SLDPRT
CAD/Obsoletos/SolidWorks/Chave.SLDPRT
CAD/Obsoletos/SolidWorks/Haste.SLDPRT
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

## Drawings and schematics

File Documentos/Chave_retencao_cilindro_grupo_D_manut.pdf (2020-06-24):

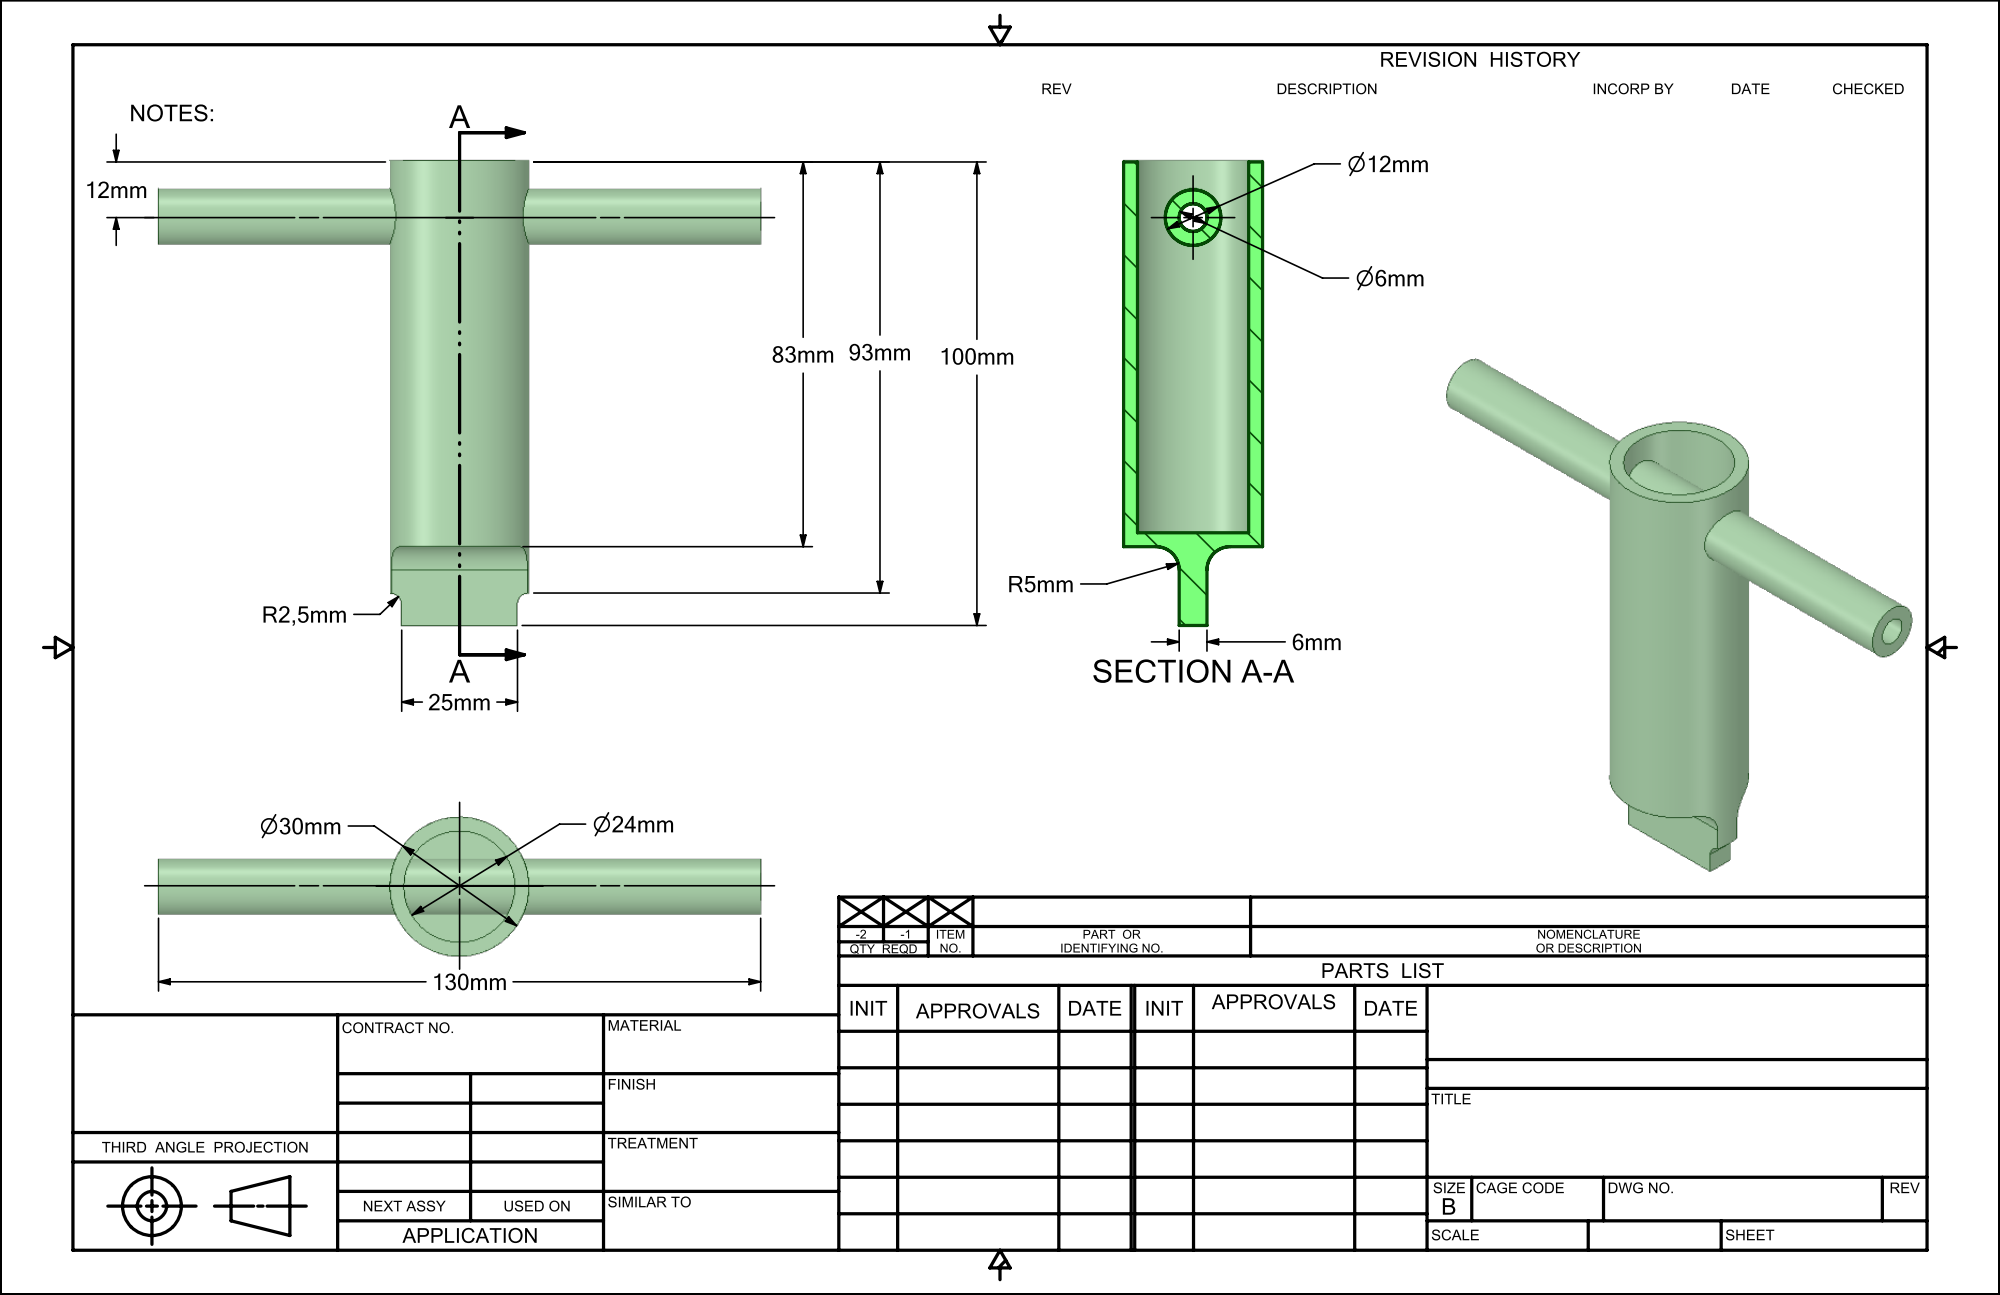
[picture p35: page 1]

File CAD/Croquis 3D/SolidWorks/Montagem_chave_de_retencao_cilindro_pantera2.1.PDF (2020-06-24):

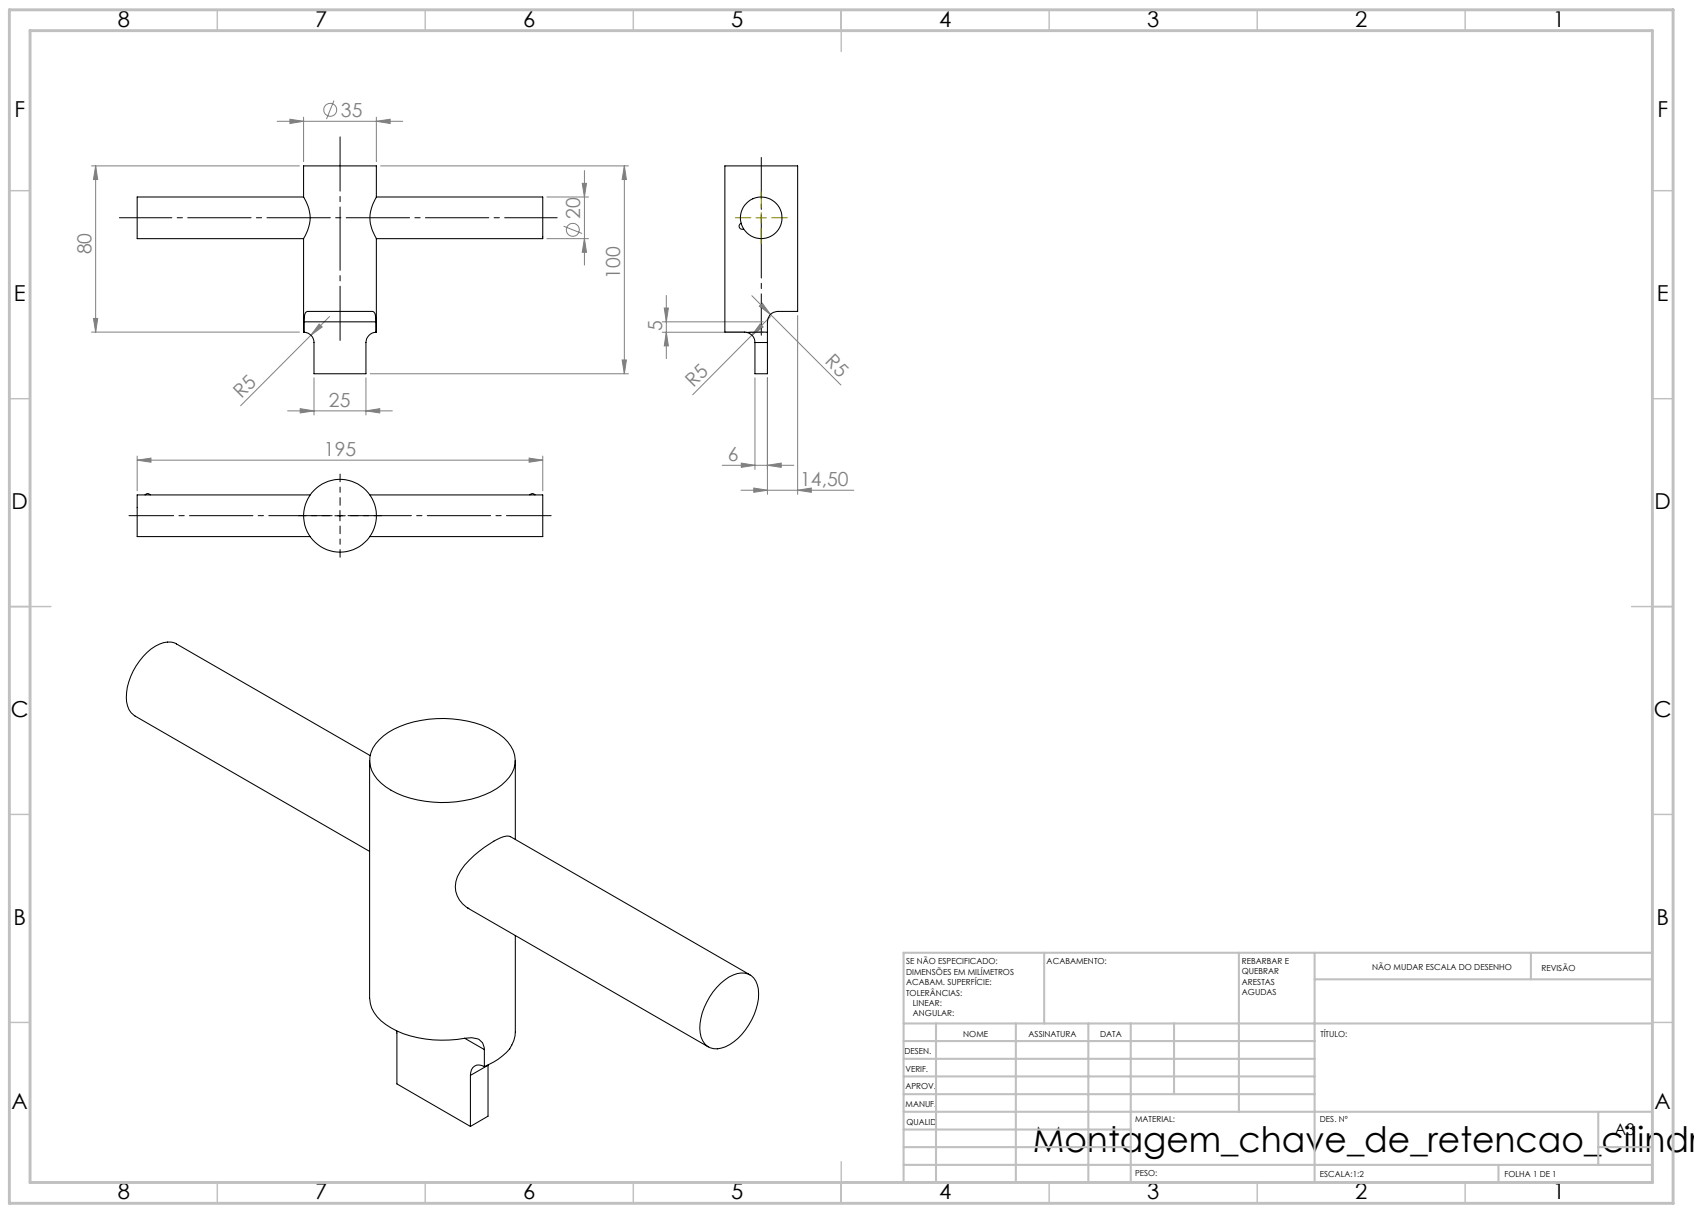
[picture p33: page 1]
ACABAMENTO:; REBARBAR E; NÃO MUDAR ESCALA DO DESENHO; REVISÃO; ESCALA:1:2; FOLHA 1 DE 1

SE NÃO ESPECIFICADO:
DIMENSÕES EM MILÍMETROS
ACABAM. SUPERFÍCIE:
TOLERÂNCIAS:
LINEAR:
ANGULAR:

NOME | ASSINATURA | DATA | | | | TÍTULO:

DESEN.
VERIF.
APROV.
MANUF.
QUALID | | | | MATERIAL: | DES. Nº | A3

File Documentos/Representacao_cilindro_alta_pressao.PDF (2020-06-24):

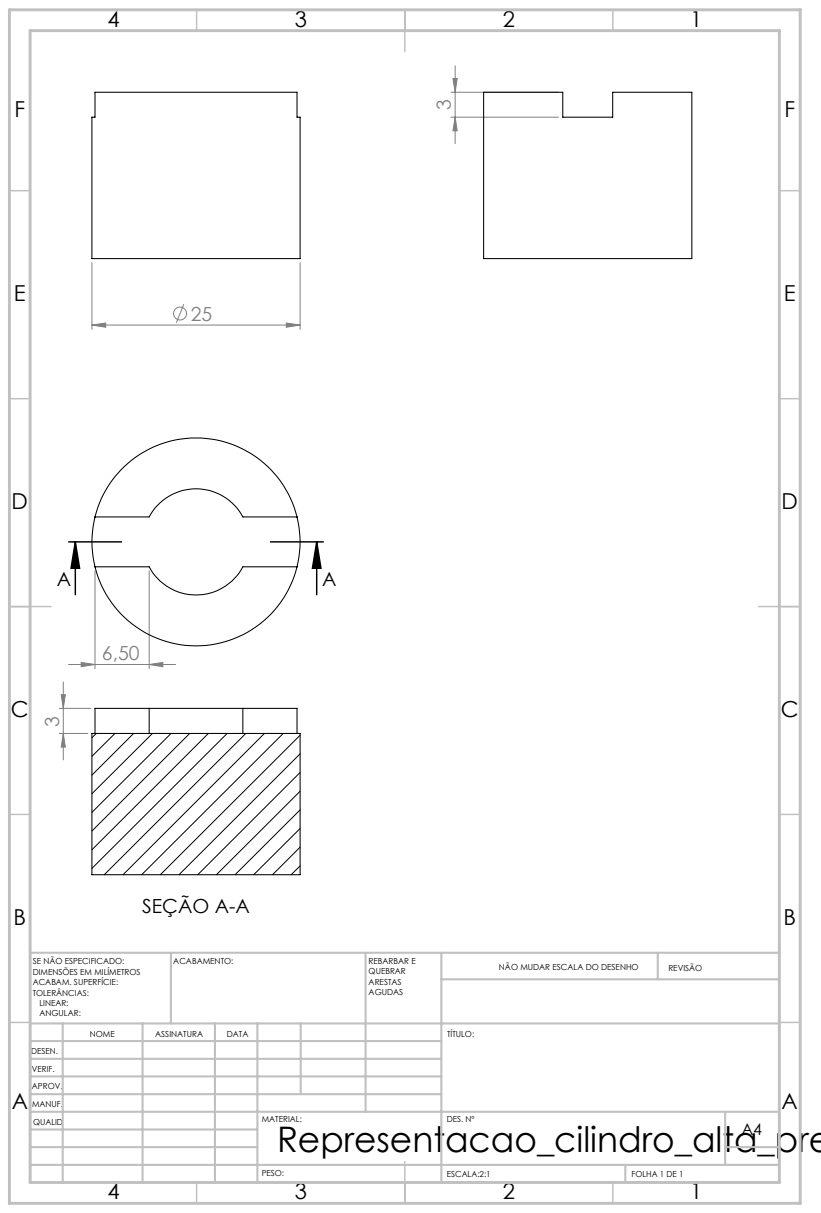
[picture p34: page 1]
SEÇÃO A-A; ACABAMENTO:; REBARBAR E; NÃO MUDAR ESCALA DO DESENHO; REVISÃO; ESCALA:2:1; FOLHA 1 DE 1

SE NÃO ESPECIFICADO:
DIMENSÕES EM MILÍMETROS
ACABAM. SUPERFÍCIE:
TOLERÂNCIAS:
LINEAR:
ANGULAR:

NOME | ASSINATURA | DATA | | | | TÍTULO:

DESEN.
VERIF.
APROV.
MANUF.
QUALID | | | | MATERIAL: | DES. Nº | A4
